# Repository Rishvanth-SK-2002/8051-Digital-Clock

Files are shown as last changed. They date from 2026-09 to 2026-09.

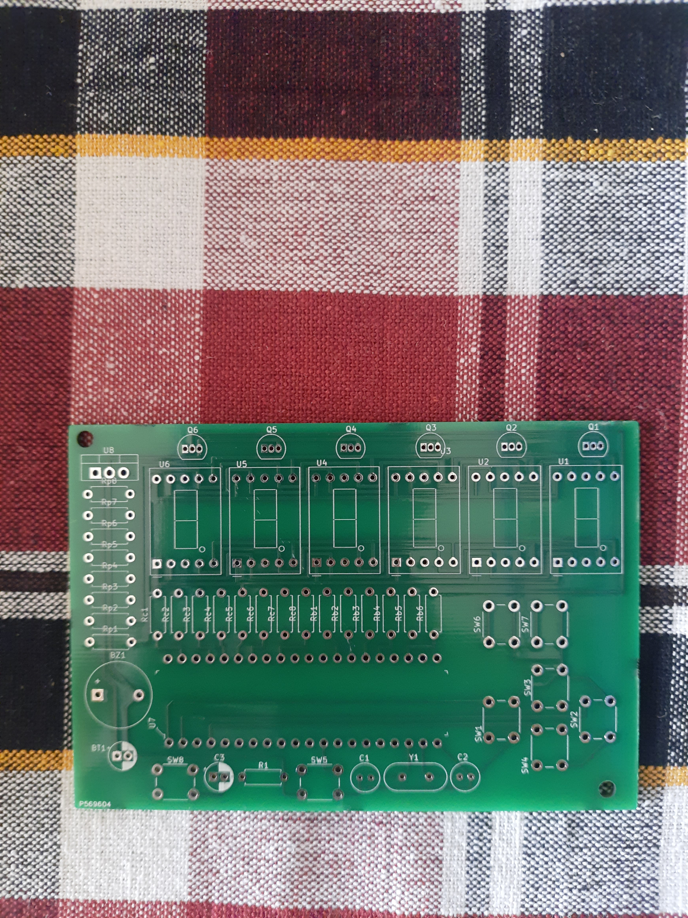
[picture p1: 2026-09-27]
media/Digclock_PCB_Unassembled.jpg

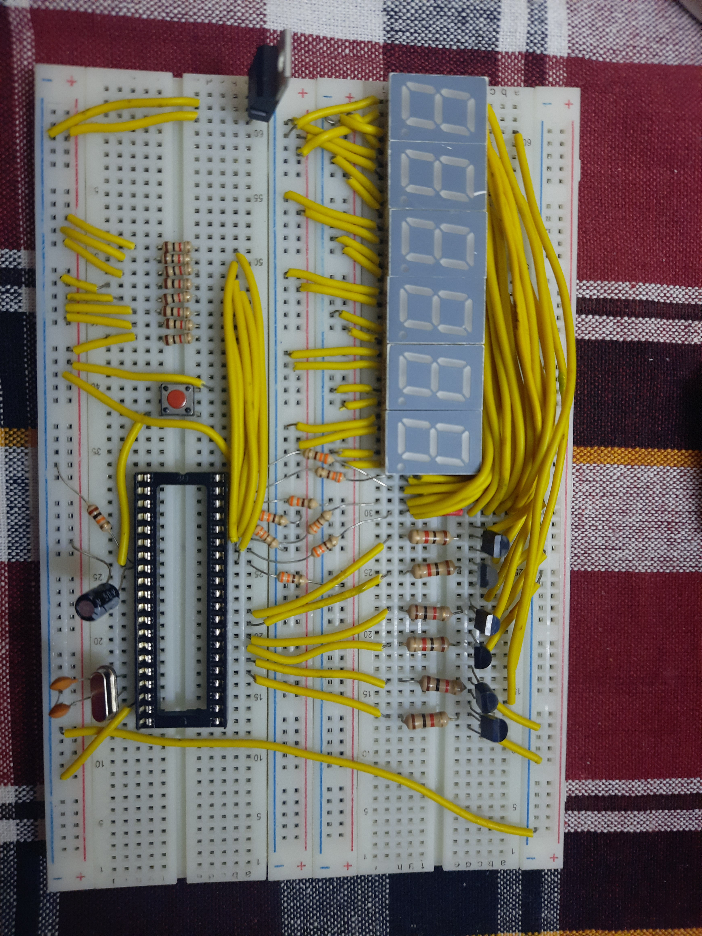
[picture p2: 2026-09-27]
media/Digclock_Breadboard.jpg

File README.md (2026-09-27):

# 8051 Digital Clock with Alarm

A bare-metal digital clock and alarm project built around the Nuvoton **W78E052DDG**, an 8051-compatible microcontroller. The project combines firmware, a custom two-layer through-hole PCB, display multiplexing, push-button UI, an audible alarm, and multiple PCB revisions.

## Project highlights

- Nuvoton W78E052DDG 8051-compatible MCU
- 11.0592 MHz clock source
- Six multiplexed 7-segment displays
- Six discrete BC547 digit drivers
- 6-position user interface: LEFT / RIGHT / UP / DOWN / MODE / TIMESET/ALARM selection
- Timer0-driven software time base
- External interrupt 0 used for entering configuration mode
- Alarm time comparison and buzzer output
- 2-layer through-hole PCB developed through multiple revisions
- Final PCB source, schematic, and manufacturing Gerbers included
- Firmware is written in 8051 assembly

## Repository structure

```text
.
├── firmware/
│   ├── digclock.asm
│   ├── MEMORY_MAP.md
│   ├── FIRMWARE_ARCHITECTURE.md
│   ├── README.md
├── hardware/
│   ├── schematic/
│   │   ├── digclock.kicad_sch
│   │   ├── digclock.kicad_pro
│   │   ├── digclock-eagle-import.kicad_sym
│   │   └── sym-lib-table
│   ├── pcb/
│   │   ├── final/
│   │   │   └── digclock.kicad_pcb
│   │   └── revisions/
│   │       ├── v1/digclockv1.kicad_pcb
│   │       ├── v2/digclockv2.kicad_pcb
│   │       ├── v3/digclockv3.kicad_pcb
│   │       └── v4/digclockv4.kicad_pcb
│   ├── fabrication/
│   │   ├── gerbers_final/
│   │   └── historical/
│   │       ├── v2/
│   │       └── v4/
│   ├── README.md
│   └── PCB_DESIGN_HISTORY.md
├── media/
│   └── Digclock_Enclosed.jpg
│   ├── Digclock_PCBA.jpg
│   ├── Digclock_PCB_Unassembled.jpg
│   └── Digclock_Breadboard.jpg
```

## Firmware architecture

The firmware uses two primary interrupts:

- **INT0 / P3.2**: enters the time/alarm setting interface and temporarily stops Timer0.
- **Timer0 overflow**: updates the software clock counters.

The main loop multiplexes the six displays and checks the alarm buffer against the current six-byte clock field.

The software time base uses Timer0 Mode 1 with a reload of **EFDBH**. That corresponds to 4133 timer counts. Assuming the project's 11.0592 MHz oscillator is operated in conventional 12T mode, one overflow is approximately 4.4846 ms and 223 overflows are nominally about 1.000064 s before accounting for exact interrupt/instruction overhead.

## Hardware architecture

The display uses a shared segment bus on **P0** and six digit-select controls on **P2.7 through P2.2**. The digit-select outputs drive six transistor stages so that only one display position is active at a time.

The user-interface and alarm connections are:

| MCU pin | Function |
|---|---|
| P1.0 | LEFT |
| P1.1 | RIGHT |
| P1.2 | UP |
| P1.3 | DOWN |
| P1.4 | BUZZER |
| P2.0 | ALARM mode select |
| P2.1 | TIMESET mode select |
| P3.2 / INT0 | MODE / configuration interrupt |
| P0 | 7-segment segment bus |
| P2.7..P2.2 | Digit select 1..6 |

## PCB development

The repository deliberately keeps the numbered PCB revisions because this was the first PCB project and the revisions document the design process. The revision history is described in `hardware/PCB_DESIGN_HISTORY.md`.

The current manufacturing output is in:

```text
hardware/fabrication/gerbers_final/
```

The final source PCB is:

```text
hardware/pcb/final/digclock.kicad_pcb
```

## Opening the KiCad project

Open `hardware/schematic/digclock.kicad_pro` in KiCad. The PCB can then be opened from the project or directly from `hardware/pcb/final/digclock.kicad_pcb`.

The revision `.kicad_pcb` files are retained as historical snapshots and do not need to be used for the final board.

## Important schematic note

For ease of schematic development and unavailability of the actual IC's symbol, an imported symbol of PIC MCU was used.

Before using the schematic as the starting point for a new design, verify the MCU pin mapping against the **W78E052DDG datasheet** and the final PCB routing.

## Photos / project presentation

Photos of the stage-by-stage progression of this project are uploaded for reference as mentioned below.

1. System wired using a breadboard.
2. PCB fabricated using the final version design but unassembled
3. Components Assembled PCB
4. Assembled PCB enclosed in a 3D-printed Enclosure.

The 3D-printed enclosure was designed by a collaborator.

## Engineering context

This project demonstrates a complete small embedded product workflow:

**requirements → schematic → PCB placement/routing → revision → firmware → bring-up/debug → assembled hardware → enclosure integration**

The firmware is intentionally retained at the assembly level so the implementation details of interrupts, timer configuration, register banks, indirect addressing, table lookup, multiplexing, and bare-metal UI logic remain visible.

## References

- Nuvoton W78E052D / W78E054D datasheet: https://www.nuvoton.com/resource-files/W78E054D_W78E052D_A13.pdf
- KiCad project files: see `hardware/`

## License

No license is asserted by this repository yet.

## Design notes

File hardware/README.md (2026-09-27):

# Hardware / PCB

The hardware is a two-layer, through-hole digital clock and alarm board designed in KiCad.

## Source files

The final design consists of:

* schematic: `schematic/digclock.kicad\_sch`
* KiCad project: `schematic/digclock.kicad\_pro`
* final PCB layout: `pcb/final/digclock.kicad\_pcb`
* historical PCB revisions: `pcb/revisions/v1` through `v4`
* final fabrication outputs: `fabrication/gerbers\_final`

## Final PCB

The final PCB file in this repository is approximately **97 mm × 67 mm**.

The project uses through-hole components including the MCU, 7-segment displays, BC547 transistor stages, resistors, capacitors, crystal, regulator, switches, buzzer, and battery connector.

## Revision files

The numbered revisions are retained as design-history snapshots. See `PCB\_DESIGN\_HISTORY.md` for the evolution details.

## Fabrication

The `gerbers\_final` directory contains the final Gerber and drill outputs supplied with the project. These are the files to inspect with a Gerber viewer before sending a board to fabrication.

Do not edit Gerbers manually to modify the electrical design. Make changes in the KiCad schematic/PCB source, run design-rule checks, and regenerate fabrication outputs.

## Reusing the design

Before manufacturing another batch:

1. Open the final project in KiCad.
2. Verify the schematic-to-PCB consistency.
3. Run ERC/DRC using the rules appropriate for the intended manufacturer.
4. Inspect Edge.Cuts, drill files, silkscreen, and all copper layers in a Gerber viewer.
5. Confirm the W78E052DDG pin mapping.
6. Confirm component availability and footprints.
7. Generate a fresh fabrication package from the final PCB rather than relying on historical Gerbers.

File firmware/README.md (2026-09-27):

# Firmware

The firmware is a bare-metal 8051 assembly implementation for the Nuvoton W78E052DDG.

## Main functions

`MAIN`
: Initializes the stack, I/O aliases, Timer0, interrupts, lookup table pointer, clock state, and timer preload.

`ENDLESS`
: Multiplexes the six 7-segment digits and compares the live clock field against the alarm field.

`ISRT0`
: Services Timer0 overflow, builds the approximately one-second software time base, and rolls seconds/minutes/hours.

`MODESELECT`
: Enters the configuration interface through INT0 and selects time-setting or alarm-setting mode.

`SETMODE`
: Handles cursor movement, digit editing, display refresh, and exit from configuration mode.

`TERMINATE`
: Restores the selected representation, restarts Timer0, and returns through the common interrupt-context restoration path.

`RADDX`
: Adds `R4` to `R0`.

`ADDX`
: Adds `R5` to the byte addressed by `R0`.

`DEBOUNCE`
: Implements a simple software delay used after button activity.

## 8051 concepts demonstrated

* fixed reset/interrupt vectors
* `LJMP`, `LCALL`, `RETI`
* Timer0 Mode 1
* external interrupt INT0
* register banks via PSW `RS1:RS0`
* direct and indirect internal-RAM addressing
* `MOVC` table lookup from code memory
* `CJNE` and carry-based unsigned comparison
* software counters and rollover logic
* multiplexed 7-segment display control
* software button debouncing
* two's-complement subtraction via `ADD`

## Timer calculation

```text
Fosc = 11.0592 MHz
12T timer tick = 12 / Fosc
               ≈ 1.085069 µs

Timer0 preload = EFDBH
Counts         = 65536 - EFDBH
               = 4133

One overflow  = 4133 × 1.085069 µs
               ≈ 4.484592 ms

223 overflows = 223 × 4.484592 ms
               ≈ 1.000064 s
```

The calculation is a nominal oscillator/timer calculation. Actual clock accuracy is also affected by the oscillator source and implementation details around interrupt handling and reload timing.

## Toolchain note

The repository does not include the original assembler/project build configuration. The source uses conventional 8051 assembly syntax and should be assembled with a compatible 8051 assembler after verifying any syntax-specific requirements of the chosen toolchain. Do not assume that every assembler accepts every directive or negative-immediate spelling identically.

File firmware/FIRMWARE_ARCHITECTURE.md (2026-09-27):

# Firmware Architecture

## Top-level flow

```text
Reset
  |
  v
MAIN
  |
  +--> initialize Timer0 / interrupts / lookup table
  |
  +--> ENDLESS ----------------------------+
  |      |                                  |
  |      +--> multiplex six displays       |
  |      +--> compare clock vs alarm        |
  |                                         |
  +<-----------------------------------------+

INT0 / MODE button
  |
  v
MODESELECT
  |
  +--> Alarm selected -> copy clock field to alarm field
  |
  +--> Time selected  -> edit live clock field
  |
  v
SETMODE
  |
  +--> LEFT / RIGHT : move selected position
  +--> UP / DOWN     : modify selected value
  +--> display refresh
  +--> MODE          : exit
  |
  v
TERMINATE
  |
  +--> restore representation
  +--> restore saved context
  +--> reload/restart Timer0
  |
  v
RETI

Timer0 overflow
  |
  v
ISRT0
  |
  +--> reload Timer0
  +--> R6++
  +--> every 223 overflows -> advance clock
  +--> seconds -> minutes -> hours rollover
  +--> restore register-bank state
  |
  v
RETI
```

## Display subsystem

All six 7-segment positions share the segment-data bus on P0. The firmware selects one display at a time using P2.7..P2.2.

The display code is looked up from program memory with:

```asm
MOV A, Rn
MOVC A, @A+DPTR
MOV DIGIT, A
```

This is the firmware equivalent of:

```c
pattern = BITPATTERN[index];
P0 = pattern;
```

## Timekeeping subsystem

Timer0 is configured in Mode 1. A 16-bit timer period is generated from the preload `EFDBH`. A software counter in `R6` counts 223 Timer0 overflows before the calendar counters are advanced.

## Alarm subsystem

The live clock field and alarm field are stored separately. The main loop compares six bytes. If all six match, the buzzer is driven high and held for a software delay.

## Configuration subsystem

The MODE button is wired to INT0. The external interrupt is therefore the entry point to the editor. Timer0 is stopped during configuration so the normal timekeeping routine does not continue advancing the clock while values are being edited.

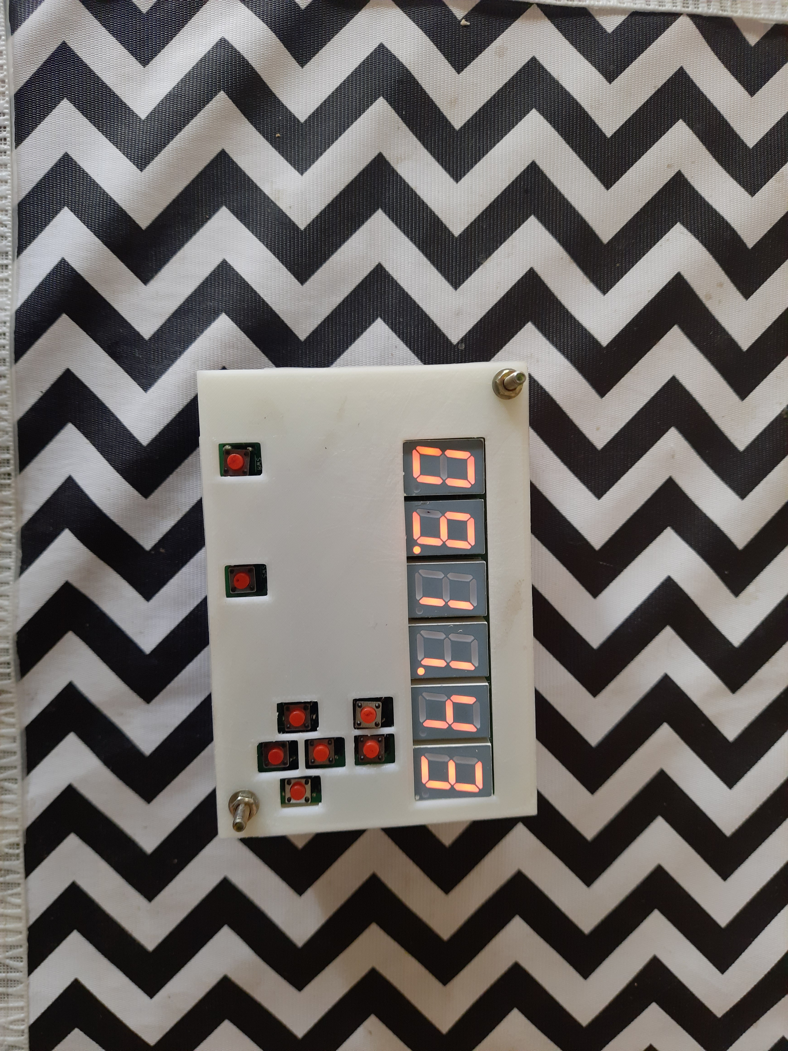
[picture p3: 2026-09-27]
media/Digclock_Enclosed.jpg

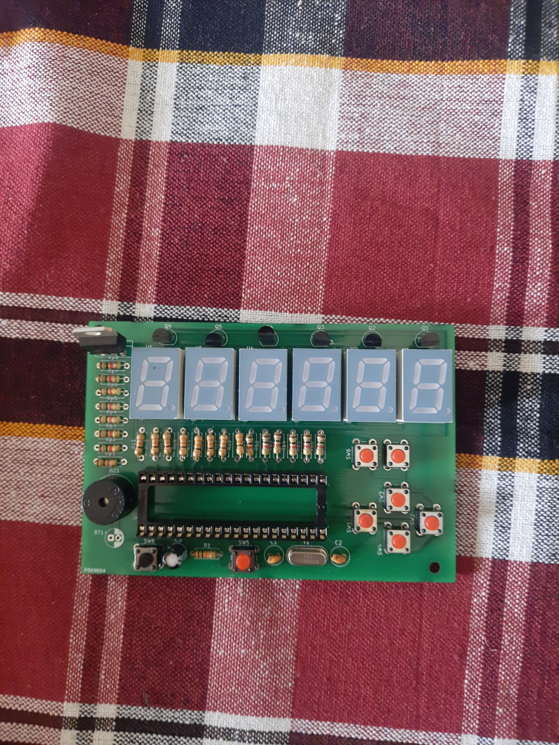
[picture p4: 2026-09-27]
media/Digclock_PCBA.jpg

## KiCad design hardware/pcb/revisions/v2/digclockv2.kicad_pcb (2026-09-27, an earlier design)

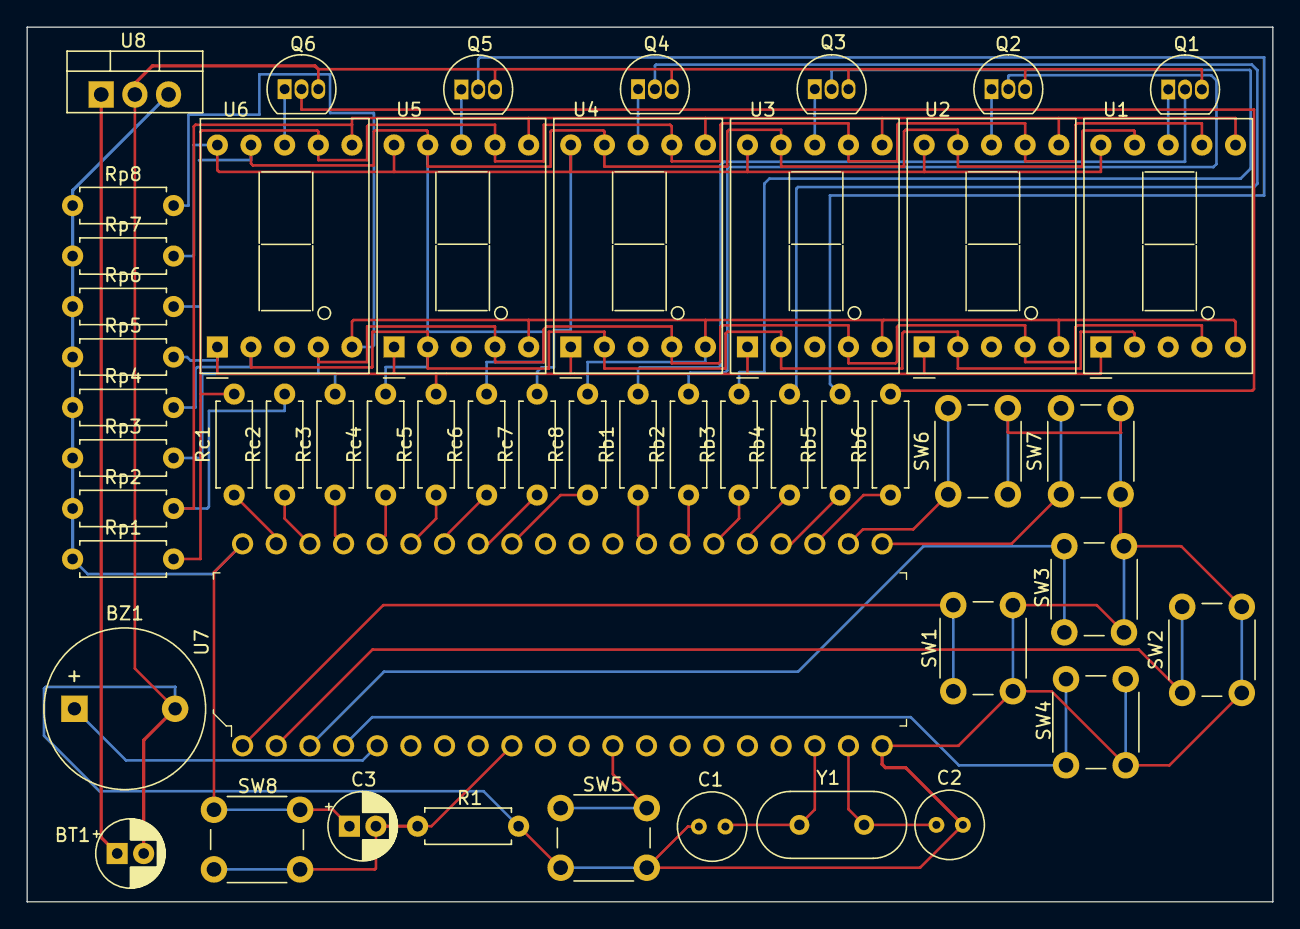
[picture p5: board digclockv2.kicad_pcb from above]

Board: 2 copper layers, 94.0 x 66.0 mm, 51 parts (0 on the bottom side), 48 nets.

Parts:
BT1: 9V; CP_Radial_D5.0mm_P2.00mm
BZ1: Buzzer; Buzzer_12x9.5RM7.6
C1, C2: 33pF; C_Radial_D5.0mm_H5.0mm_P2.00mm
C3: 10uF; CP_Radial_D5.0mm_P2.00mm
Q1, Q2, Q3, Q4, Q5, Q6: BC547; TO-92_Inline
R1: 10k; R_Axial_DIN0207_L6.3mm_D2.5mm_P7.62mm_Horizontal
Rb1, Rb2, Rb3, Rb4, Rb5, Rb6: 1k; R_Axial_DIN0207_L6.3mm_D2.5mm_P7.62mm_Horizontal
Rc1, Rc2, Rc3, Rc4, Rc5, Rc6, Rc7, Rc8: 330; R_Axial_DIN0207_L6.3mm_D2.5mm_P7.62mm_Horizontal
Rp1, Rp2, Rp3, Rp4, Rp5, Rp6, Rp7, Rp8: 1k; R_Axial_DIN0207_L6.3mm_D2.5mm_P7.62mm_Horizontal
SW1: LEFT; SW_PUSH_6mm
SW2: RIGHT; SW_PUSH_6mm
SW3: UP; SW_PUSH_6mm
SW4: DOWN; SW_PUSH_6mm
SW5: MODE; SW_PUSH_6mm
SW6: TIMESET; SW_PUSH_6mm
SW7: ALARM; SW_PUSH_6mm
SW8: RESET; SW_PUSH_6mm
U1, U2, U3, U4, U5, U6: D168K; D1X8K
U7: W78E052DDG; DIP-40_W15.24mm
U8: LM7805; TO-220-3_Vertical
Y1: 11.0592Mhz; Crystal_HC49-U_Vertical

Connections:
unnamed: BT1.1 (+), U8.1 (VI)
unnamed: BT1.2 (-), BZ1.2 (+), C1.1, C2.1, Q1.3 (E), Q2.3 (E), Q3.3 (E), Q4.3 (E), Q5.3 (E), Q6.3 (E), R1.1, SW1.1, SW2.2, SW3.2, SW4.2, SW5.1, SW6.2, SW7.2, U7.20 (GND), U8.2 (GND)
unnamed: BZ1.1 (-), U7.5 (P1.4)
unnamed: C1.2, U7.18 (XTAL2), Y1.2
unnamed: C2.2, U7.19 (XTAL1), Y1.1
unnamed: C3.1, Rp1.1, Rp2.1, Rp3.1, Rp4.1, Rp5.1, Rp6.1, Rp7.1, Rp8.1, SW8.2, U7.40 (VCC), U8.3 (VO)
unnamed: C3.2, R1.2, SW8.1, U7.9 (RST)
unnamed: Q1.1 (C), U1.8 (CC)
unnamed: Q1.2 (B), Rb1.2
unnamed: Q2.1 (C), U2.8 (CC)
unnamed: Q2.2 (B), Rb2.2
unnamed: Q3.1 (C), U3.8 (CC)
unnamed: Q3.2 (B), Rb3.2
unnamed: Q4.1 (C), U4.8 (CC)
unnamed: Q4.2 (B), Rb4.2
unnamed: Q5.1 (C), U5.8 (CC)
unnamed: Q5.2 (B), Rb5.2
unnamed: Q6.1 (C), U6.8 (CC)
unnamed: Q6.2 (B), Rb6.2
unnamed: Rb1.1, U7.28 (P2.7(A15))
unnamed: Rb2.1, U7.27 (P2.6(A14))
unnamed: Rb3.1, U7.26 (P2.5(A13))
unnamed: Rb4.1, U7.25 (P2.4(A12))
unnamed: Rb5.1, U7.24 (P2.3(A11))
unnamed: Rb6.1, U7.23 (P2.2(A10))
unnamed: Rc1.1, U7.39 (P0.0(AD0))
unnamed: Rc1.2, Rp1.2, U1.7 (A), U2.7 (A), U3.7 (A), U4.7 (A), U5.7 (A), U6.7 (A)
unnamed: Rc2.1, U7.38 (P0.1(AD1))
unnamed: Rc2.2, Rp2.2, U1.6 (B), U2.6 (B), U3.6 (B), U4.6 (B), U5.6 (B), U6.6 (B)
unnamed: Rc3.1, U7.37 (P0.2(AD2))
unnamed: Rc3.2, Rp3.2, U1.4 (C), U2.4 (C), U3.4 (C), U4.4 (C), U5.4 (C), U6.4 (C)
unnamed: Rc4.1, U7.36 (P0.3(AD3))
unnamed: Rc4.2, Rp4.2, U1.2 (D), U2.2 (D), U3.2 (D), U4.2 (D), U5.2 (D), U6.2 (D)
unnamed: Rc5.1, U7.35 (P0.4(AD4))
unnamed: Rc5.2, Rp5.2, U1.1 (E), U2.1 (E), U3.1 (E), U4.1 (E), U5.1 (E), U6.1 (E)
unnamed: Rc6.1, U7.34 (P0.5(AD5))
unnamed: Rc6.2, Rp6.2, U1.9 (F), U2.9 (F), U3.9 (F), U4.9 (F), U5.9 (F), U6.9 (F)
unnamed: Rc7.1, U7.33 (P0.6(AD6))
unnamed: Rc7.2, Rp7.2, U1.10 (G), U2.10 (G), U3.10 (G), U4.10 (G), U5.10 (G), U6.10 (G)
unnamed: Rc8.1, U7.32 (P0.7(AD7))
unnamed: Rc8.2, Rp8.2, U1.5 (DP), U2.5 (DP), U3.5 (DP), U4.5 (DP), U5.5 (DP), U6.5 (DP)
unnamed: SW1.2, U7.1 (P1.0)
unnamed: SW2.1, U7.2 (P1.1)
unnamed: SW3.1, U7.3 (P1.2)
unnamed: SW4.1, U7.4 (P1.3)
unnamed: SW5.2, U7.12 (P3.2(~INT0))
unnamed: SW6.1, U7.22 (P2.1(A9))
unnamed: SW7.1, U7.21 (P2.0(A8))

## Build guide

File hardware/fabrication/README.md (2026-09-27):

# Fabrication Outputs

`gerbers_final/` contains the final fabrication files supplied with the project.

Before sending them to a PCB manufacturer, open the Gerbers in an independent viewer and verify:

- board outline / Edge.Cuts
- front and back copper
- solder mask
- silkscreen
- paste layers if required by the assembly process
- PTH and NPTH drill files
- drill map
- intended board revision

The Gerber ZIP in this folder is a convenient packaged output. The individual files are retained so the layer set is directly inspectable in the repository.

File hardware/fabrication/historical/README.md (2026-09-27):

# Historical Fabrication Outputs

These folders contain selected older Gerber packages retained for design-history purposes.

They are **not** the primary manufacturing files. Use `../gerbers_final/` for the final board output and regenerate fabrication files from the final KiCad source when making a new production run.

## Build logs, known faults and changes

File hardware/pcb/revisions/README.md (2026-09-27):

# PCB Revisions

These files are historical KiCad PCB snapshots:

- `v1` — first large board implementation
- `v2` — major compact layout revision
- `v3` — intermediate placement/routing experiment
- `v4` — further physical/mechanical refinement

The current/final board is kept separately under `../final/`.

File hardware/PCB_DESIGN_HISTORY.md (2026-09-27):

# PCB Design History

The repository contains several layouts because this was my first PCB design and the board went through multiple physical revisions.

The electrical component inventory is the same across all the versions as the revisions focus primarily on placement, routing, board dimensions, and mechanical refinement rather than fundamental circuit redesigns.

## Revision dimensions and routing density

| Revision | Board size | Routed segments in file* | Interpretation |
|---|---:|---:|---|
| V1 | 130 × 95 mm | 392 | Initial large-board implementation |
| V2 | 94 × 66 mm | 470 | Major size reduction and routing optimization |
| V3 | 113.03 × 66 mm | 41 | Intermediate layout experiment / incomplete routing snapshot |
| V4 | 102 × 70 mm | 497 | Further placement/mechanical refinement |
| Final | 97 × 67 mm | 470 | Compact final layout with mounting-hole refinement |

\* Routed segment counts are included as an objective file-level comparison, not as a measure of PCB quality.

## Development story

### V1

This was the first physical implementation of the working circuit, ensuring the component placements and fully traced layouts, but with no regard to spacing constraints. Trace width was about 10 mils.

### V2

This was a try at achieving a more compact form factor than the first version, decreasing the trace widths to 7.84 mils, placing the components closer and routing with the traces and pads dangerously close to each other.

### V3

This version is an incomplete one. Continued and completed in version 4.

### V4

Trace widths increased to 20 mils due to a locally available manufacturer's constraints then. Mounting holes were added before finalizing the enclosure design.

### Final

The final board is approximately 97 × 67 mm and comes back to 7.84 mil traces. It is very similar to version 2 but with mounting holes and few other minor refinements in the tracing.

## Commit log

2026-09-27 Uploaded the hardware folder
    [digclock-B_Cu.gbl, digclock-B_Mask.gbs, digclock-B_Paste.gbp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]
2026-09-27 Updated PCB_DESIGN_HISTORY.md
